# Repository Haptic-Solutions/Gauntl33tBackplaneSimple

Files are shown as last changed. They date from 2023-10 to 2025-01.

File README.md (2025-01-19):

# Gauntl33tBackplaneSimple
 Simple backplane for controlling Brushless DC Gimbal motors in haptic gloves or other devices, designed at the end of 2022.  No active or passive components, just connectors.  In the future will likely make upgrades, such as taking advantage of soft I2C, but keep the board as a simple backplane.

 The Board uses SimpleFOC Mini drivers and Teensy 4.0s for controllers.

 3D Models on Printables: https://www.printables.com/model/366681-gauntl33t

 Firmware: https://github.com/Haptic-Solutions/Gauntl33tFirmware

 Demo Game: https://github.com/Haptic-Solutions/DartsGame

 Haptic Solutions Website: https://hapticsol.com

 Haptic Solutions Discord: https://discord.gg/QZYmbjJW

 Haptic Solutions Twitter: https://twitter.com/Hapticsol

 Peter Sassaman's Twitter: https://twitter.com/PeterSassaman

 Peter Sassaman's TikTok: https://www.tiktok.com/t/ZPR7QYvvF/

Link to page about SimpleFOCMini:
https://docs.simplefoc.com/simplefocmini

Link to oage about SimpleFOC:
https://simplefoc.com/

 Buy SimpleFOCMini Drivers: https://a.aliexpress.com/_mtwToBu

 Link to page about Teensy 4.0: https://www.pjrc.com/store/teensy40.html

 Buy Teensy 4.0: https://a.co/d/iZoN8jr

 Micro PSU which could be used with design to make it smaller: https://github.com/Haptic-Solutions/MicroPSU

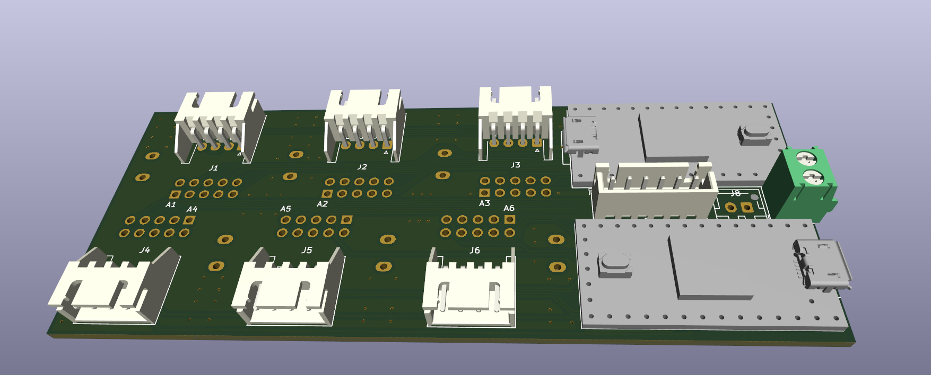
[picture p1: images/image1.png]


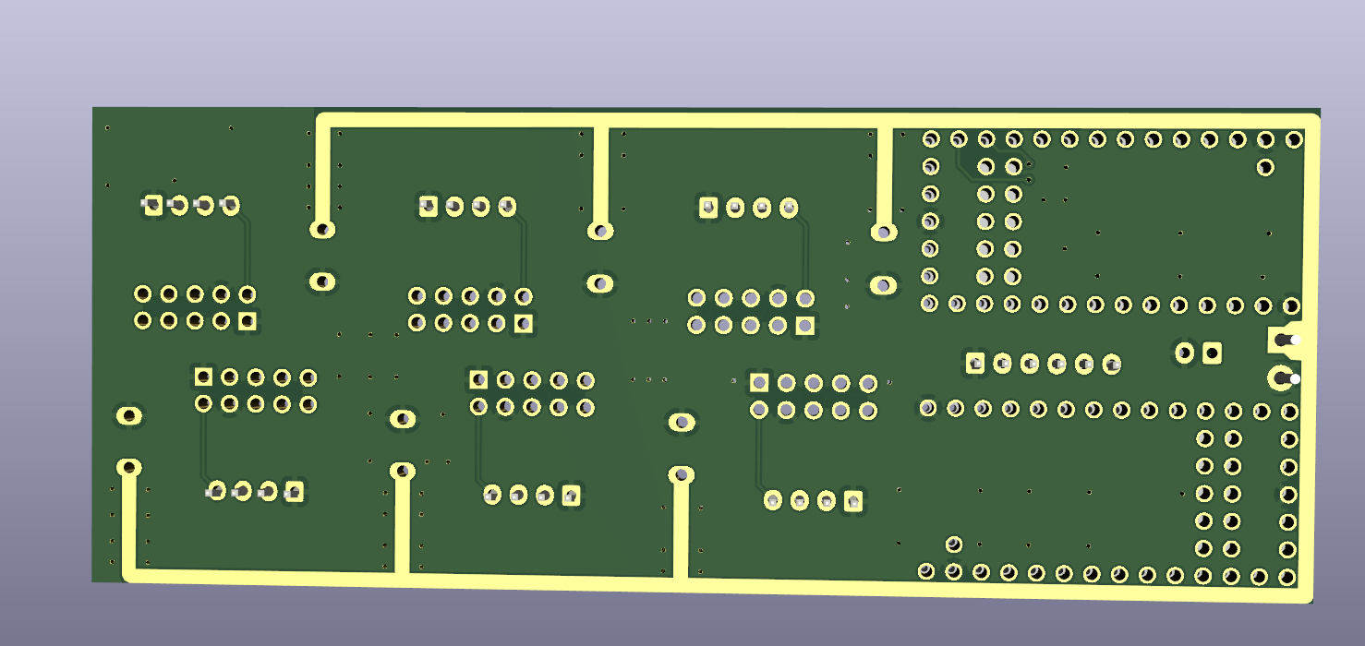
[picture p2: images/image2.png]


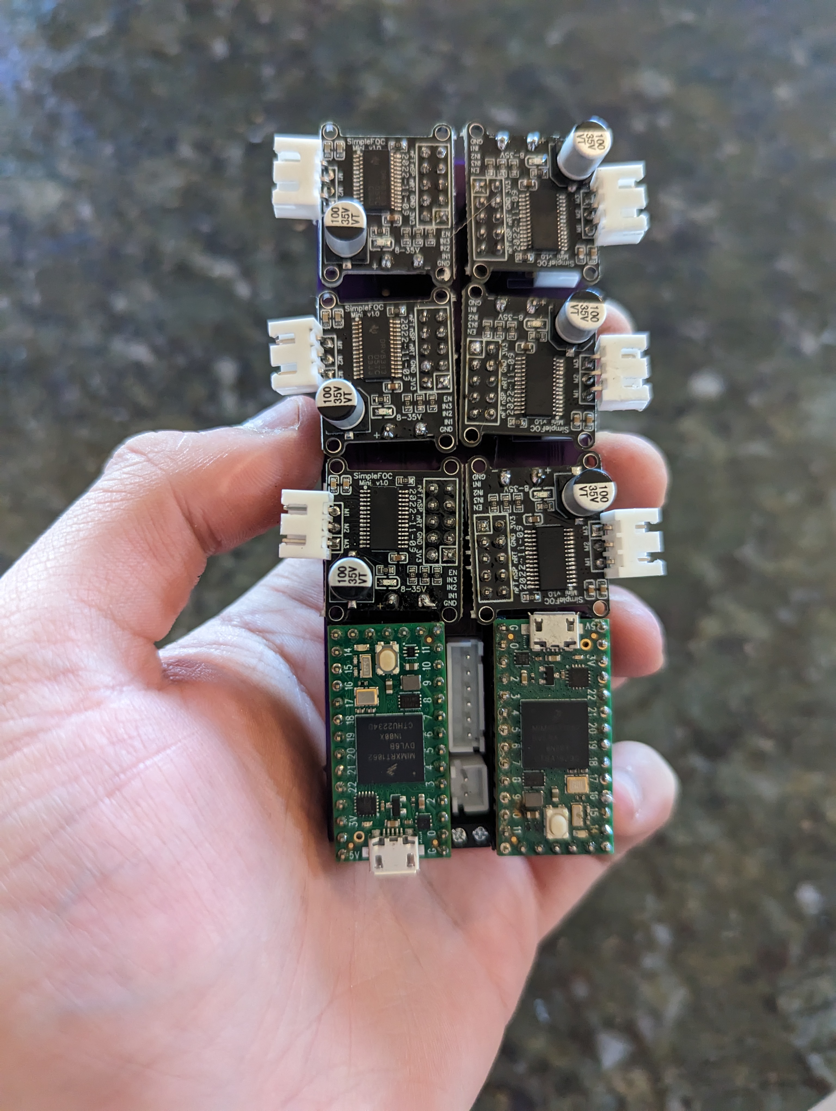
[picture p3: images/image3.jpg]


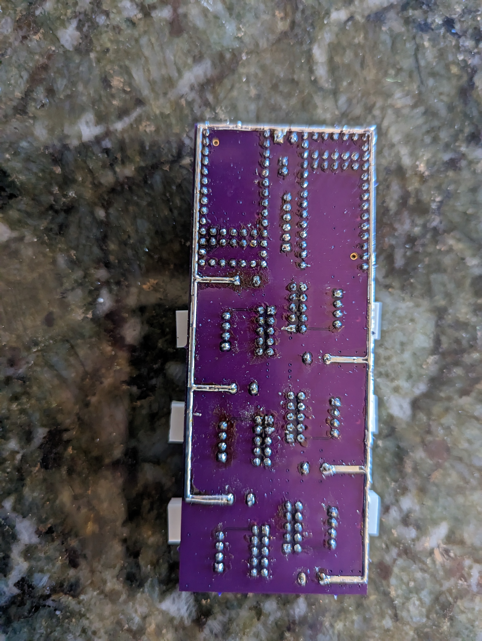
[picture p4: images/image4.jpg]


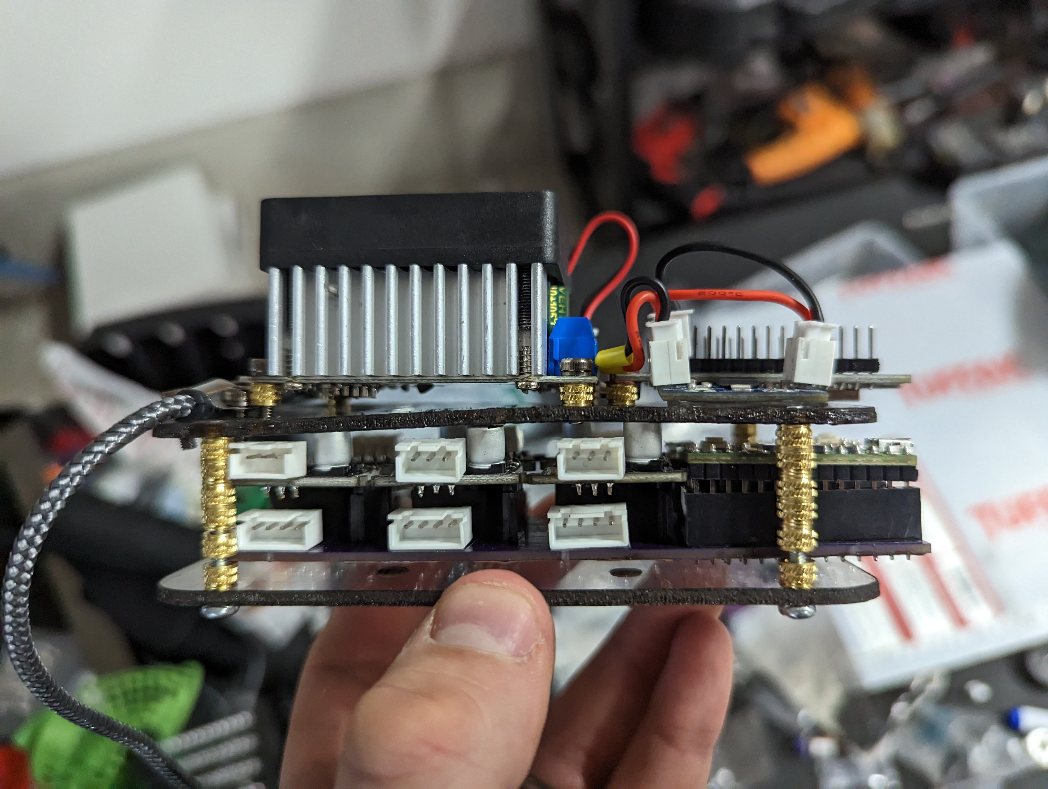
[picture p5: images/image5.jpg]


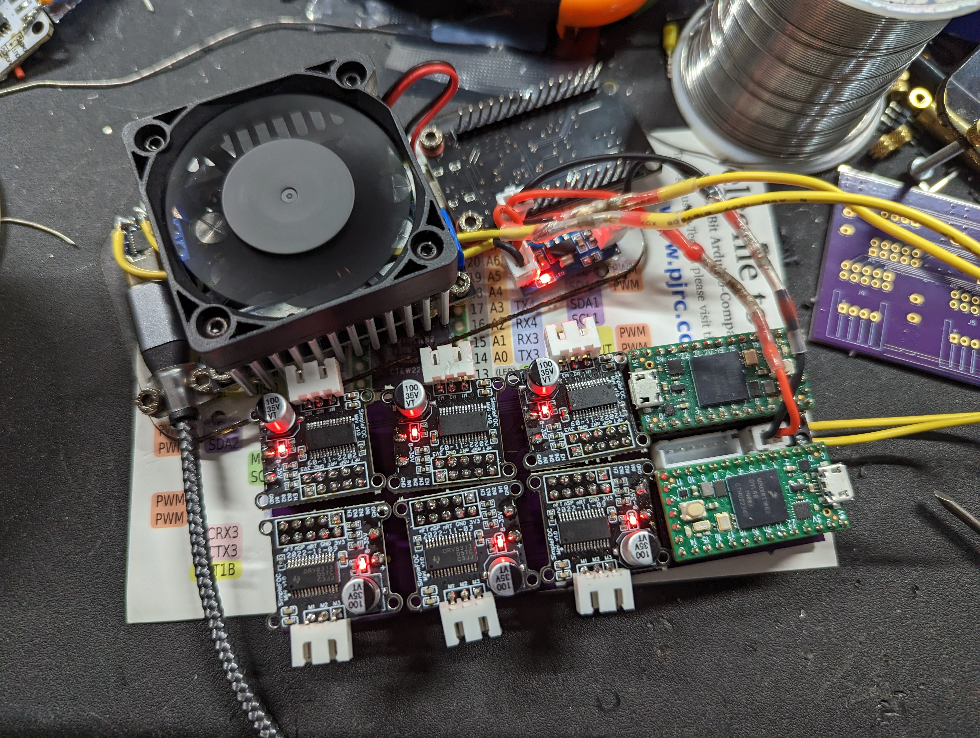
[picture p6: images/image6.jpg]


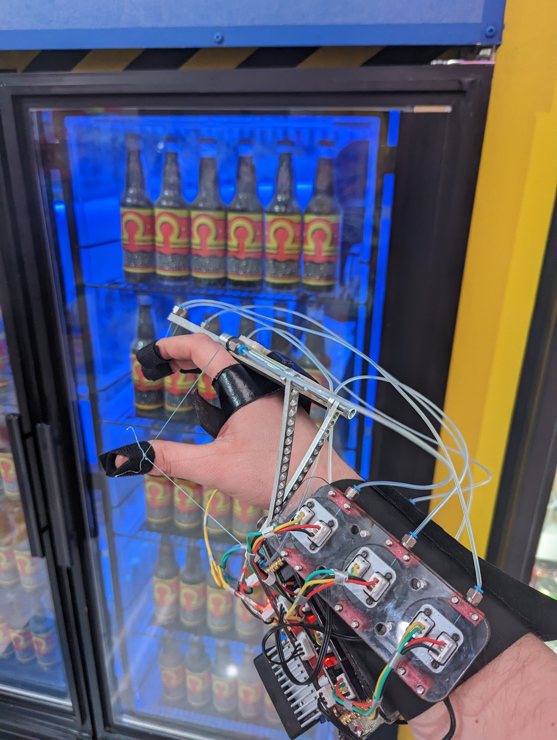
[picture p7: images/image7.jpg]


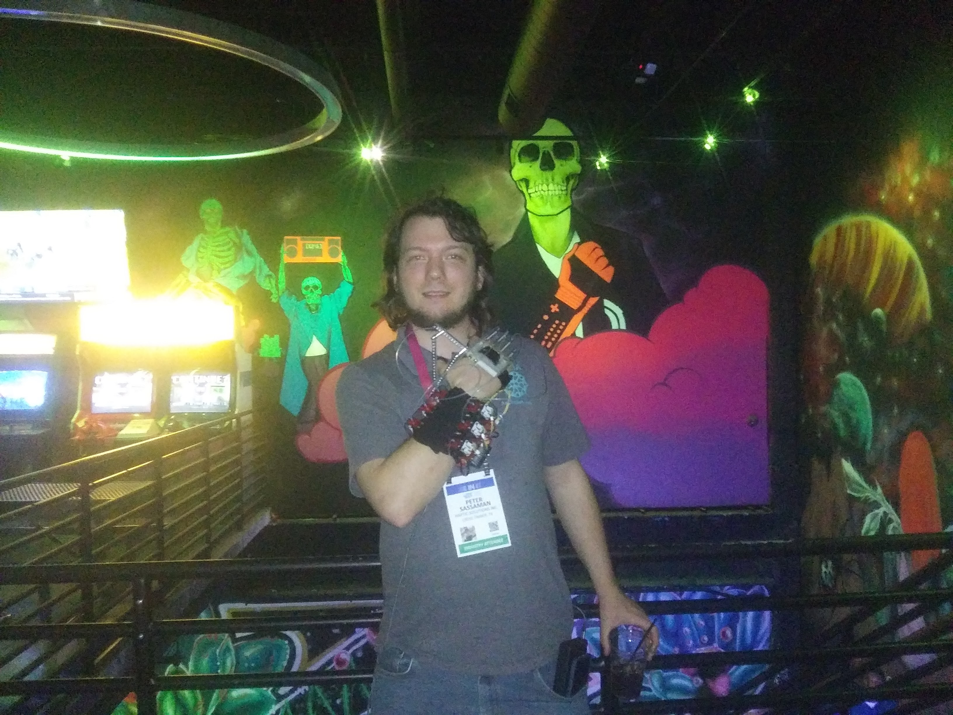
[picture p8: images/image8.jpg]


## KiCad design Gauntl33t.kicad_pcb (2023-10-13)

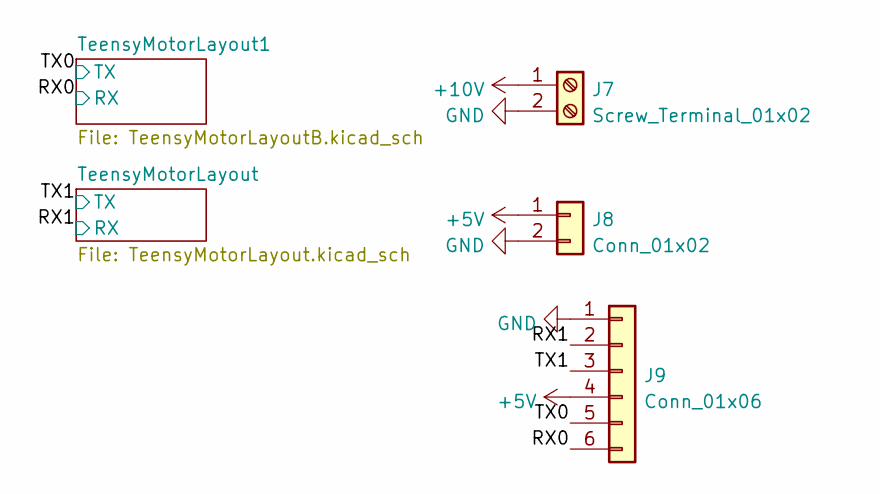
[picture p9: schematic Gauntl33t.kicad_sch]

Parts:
J7: Screw_Terminal_01x02; TerminalBlock_Phoenix_PT-1,5-2-3.5-H_1x02_P3.50mm_Horizontal
J8: Conn_01x02; JST_XH_B2B-XH-AM_1x02_P2.50mm_Vertical
J9: Conn_01x06; JST_XH_B6B-XH-A_1x06_P2.50mm_Vertical

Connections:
+5V: J8.1, J9.4; also elsewhere on the board
+10V: J7.1; also elsewhere on the board
/RX0: J9.6; also elsewhere on the board
/RX1: J9.2; also elsewhere on the board
/TX0: J9.5; also elsewhere on the board
/TX1: J9.3; also elsewhere on the board
GND: J7.2, J8.2, J9.1; also elsewhere on the board

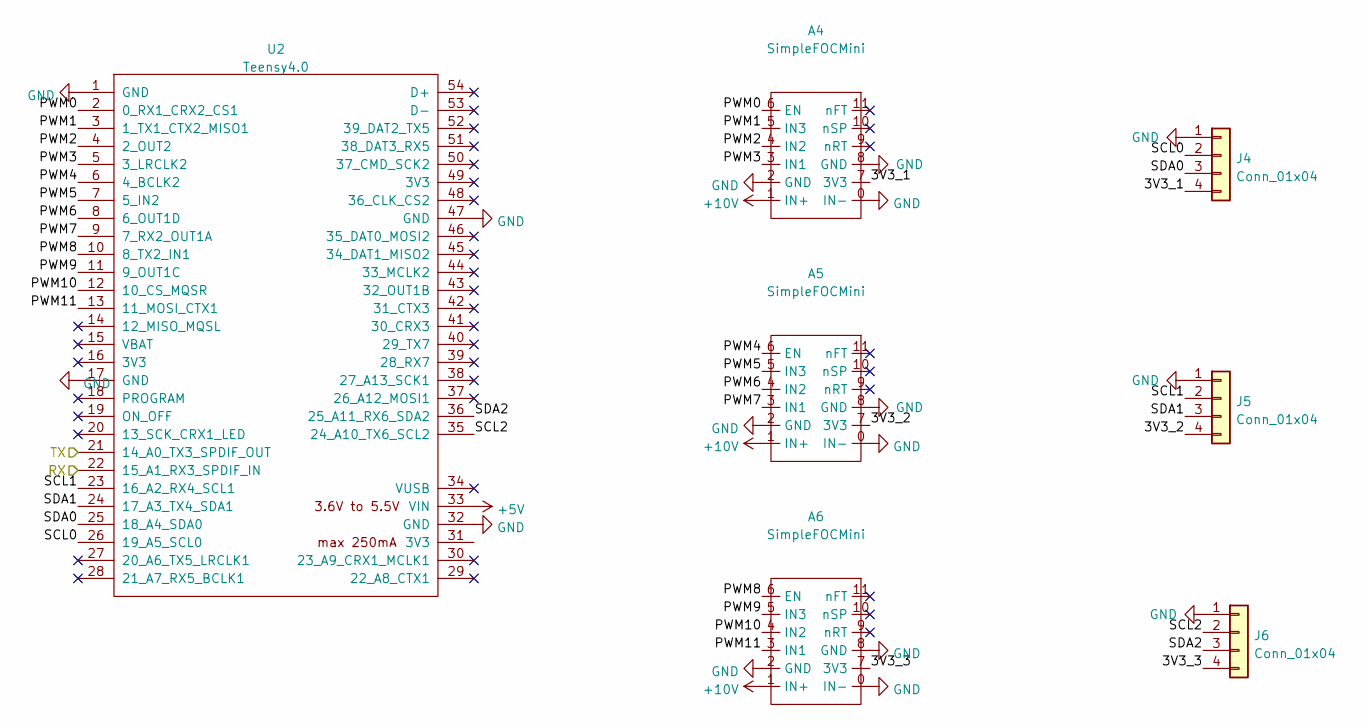
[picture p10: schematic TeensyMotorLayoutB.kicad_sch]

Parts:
A4, A5, A6: SimpleFOCMini
J4, J5, J6: Conn_01x04; JST_XH_S4B-XH-A-1_1x04_P2.50mm_Horizontal
U2: Teensy4.0; Teensy40

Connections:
+5V: U2.33 (VIN); also elsewhere on the board
+10V: A4.1 (IN+), A5.1 (IN+), A6.1 (IN+); also elsewhere on the board
/RX0: U2.22 (15_A1_RX3_SPDIF_IN); also elsewhere on the board
/TX0: U2.21 (14_A0_TX3_SPDIF_OUT); also elsewhere on the board
/TeensyMotorLayout1/3V3_1: A4.7 (3V3), J4.4
/TeensyMotorLayout1/3V3_2: A5.7 (3V3), J5.4
/TeensyMotorLayout1/3V3_3: A6.7 (3V3), J6.4
/TeensyMotorLayout1/PWM0: A4.6 (EN), U2.2 (0_RX1_CRX2_CS1)
/TeensyMotorLayout1/PWM1: A4.5 (IN3), U2.3 (1_TX1_CTX2_MISO1)
/TeensyMotorLayout1/PWM2: A4.4 (IN2), U2.4 (2_OUT2)
/TeensyMotorLayout1/PWM3: A4.3 (IN1), U2.5 (3_LRCLK2)
/TeensyMotorLayout1/PWM4: A5.6 (EN), U2.6 (4_BCLK2)
/TeensyMotorLayout1/PWM5: A5.5 (IN3), U2.7 (5_IN2)
/TeensyMotorLayout1/PWM6: A5.4 (IN2), U2.8 (6_OUT1D)
/TeensyMotorLayout1/PWM7: A5.3 (IN1), U2.9 (7_RX2_OUT1A)
/TeensyMotorLayout1/PWM8: A6.6 (EN), U2.10 (8_TX2_IN1)
/TeensyMotorLayout1/PWM9: A6.5 (IN3), U2.11 (9_OUT1C)
/TeensyMotorLayout1/PWM10: A6.4 (IN2), U2.12 (10_CS_MQSR)
/TeensyMotorLayout1/PWM11: A6.3 (IN1), U2.13 (11_MOSI_CTX1)
/TeensyMotorLayout1/SCL0: J4.2, U2.26 (19_A5_SCL0)
/TeensyMotorLayout1/SCL1: J5.2, U2.23 (16_A2_RX4_SCL1)
/TeensyMotorLayout1/SCL2: J6.2, U2.35 (24_A10_TX6_SCL2)
/TeensyMotorLayout1/SDA0: J4.3, U2.25 (18_A4_SDA0)
/TeensyMotorLayout1/SDA1: J5.3, U2.24 (17_A3_TX4_SDA1)
/TeensyMotorLayout1/SDA2: J6.3, U2.36 (25_A11_RX6_SDA2)
GND: A4.0 (IN-), A4.2 (GND), A4.8 (GND), A5.0 (IN-), A5.2 (GND), A5.8 (GND), A6.0 (IN-), A6.2 (GND), A6.8 (GND), J4.1, J5.1, J6.1, U2.1 (GND), U2.17 (GND), U2.32 (GND), U2.47 (GND); also elsewhere on the board

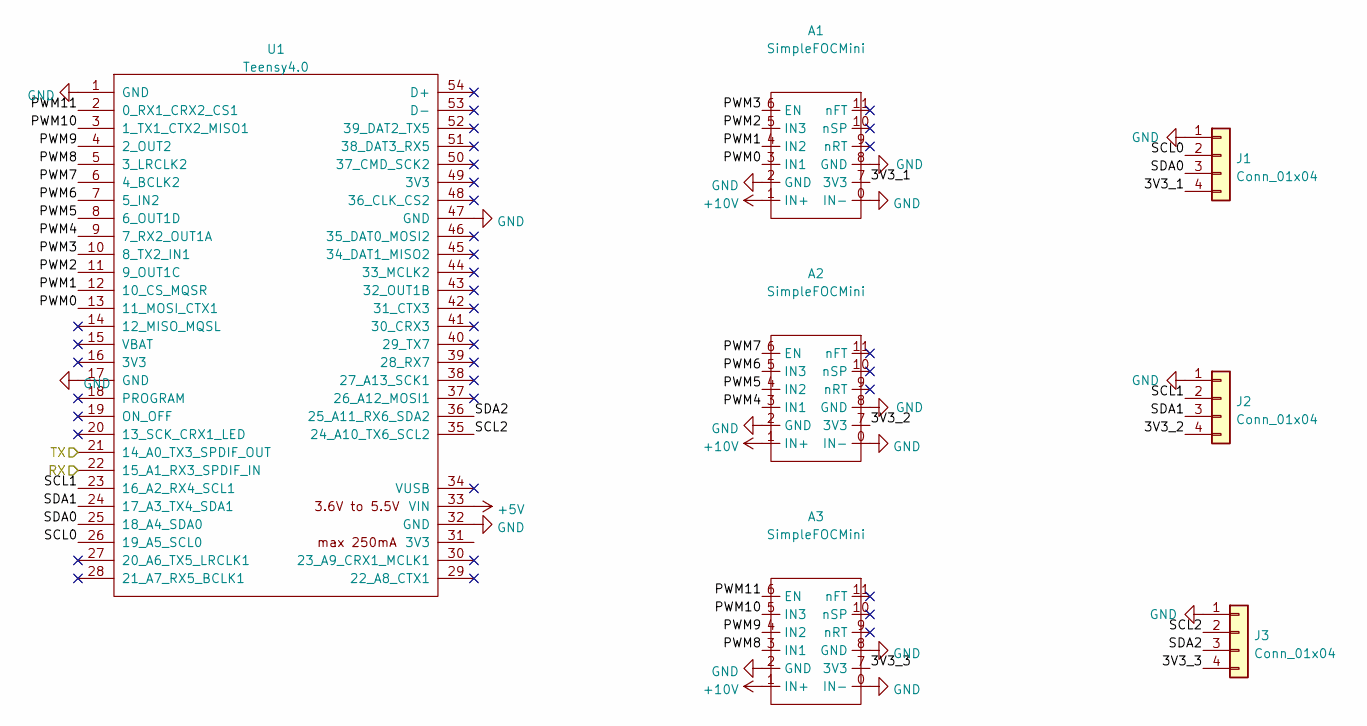
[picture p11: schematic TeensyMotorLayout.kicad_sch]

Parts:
A1, A2, A3: SimpleFOCMini
J1, J2, J3: Conn_01x04; JST_XH_S4B-XH-A-1_1x04_P2.50mm_Horizontal
U1: Teensy4.0; Teensy40

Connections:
+5V: U1.33 (VIN); also elsewhere on the board
+10V: A1.1 (IN+), A2.1 (IN+), A3.1 (IN+); also elsewhere on the board
/RX1: U1.22 (15_A1_RX3_SPDIF_IN); also elsewhere on the board
/TX1: U1.21 (14_A0_TX3_SPDIF_OUT); also elsewhere on the board
/TeensyMotorLayout/3V3_1: A1.7 (3V3), J1.4
/TeensyMotorLayout/3V3_2: A2.7 (3V3), J2.4
/TeensyMotorLayout/3V3_3: A3.7 (3V3), J3.4
/TeensyMotorLayout/PWM0: A1.3 (IN1), U1.13 (11_MOSI_CTX1)
/TeensyMotorLayout/PWM1: A1.4 (IN2), U1.12 (10_CS_MQSR)
/TeensyMotorLayout/PWM2: A1.5 (IN3), U1.11 (9_OUT1C)
/TeensyMotorLayout/PWM3: A1.6 (EN), U1.10 (8_TX2_IN1)
/TeensyMotorLayout/PWM4: A2.3 (IN1), U1.9 (7_RX2_OUT1A)
/TeensyMotorLayout/PWM5: A2.4 (IN2), U1.8 (6_OUT1D)
/TeensyMotorLayout/PWM6: A2.5 (IN3), U1.7 (5_IN2)
/TeensyMotorLayout/PWM7: A2.6 (EN), U1.6 (4_BCLK2)
/TeensyMotorLayout/PWM8: A3.3 (IN1), U1.5 (3_LRCLK2)
/TeensyMotorLayout/PWM9: A3.4 (IN2), U1.4 (2_OUT2)
/TeensyMotorLayout/PWM10: A3.5 (IN3), U1.3 (1_TX1_CTX2_MISO1)
/TeensyMotorLayout/PWM11: A3.6 (EN), U1.2 (0_RX1_CRX2_CS1)
/TeensyMotorLayout/SCL0: J1.2, U1.26 (19_A5_SCL0)
/TeensyMotorLayout/SCL1: J2.2, U1.23 (16_A2_RX4_SCL1)
/TeensyMotorLayout/SCL2: J3.2, U1.35 (24_A10_TX6_SCL2)
/TeensyMotorLayout/SDA0: J1.3, U1.25 (18_A4_SDA0)
/TeensyMotorLayout/SDA1: J2.3, U1.24 (17_A3_TX4_SDA1)
/TeensyMotorLayout/SDA2: J3.3, U1.36 (25_A11_RX6_SDA2)
GND: A1.0 (IN-), A1.2 (GND), A1.8 (GND), A2.0 (IN-), A2.2 (GND), A2.8 (GND), A3.0 (IN-), A3.2 (GND), A3.8 (GND), J1.1, J2.1, J3.1, U1.1 (GND), U1.17 (GND), U1.32 (GND), U1.47 (GND); also elsewhere on the board

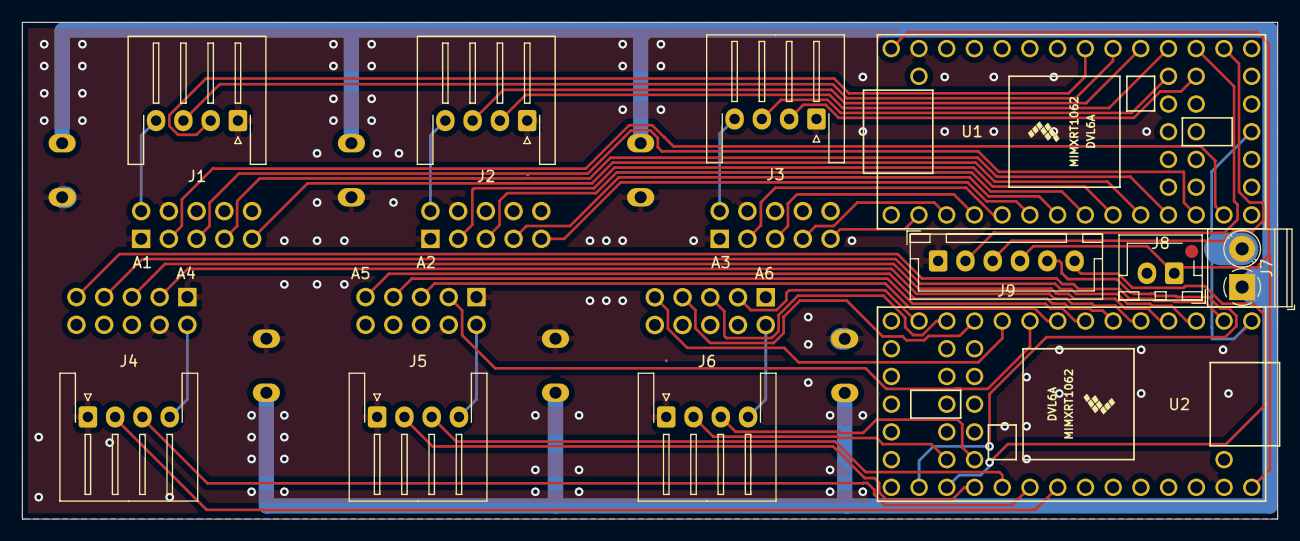
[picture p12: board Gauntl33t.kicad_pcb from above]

Board: 2 copper layers, 115.0 x 45.5 mm, 17 parts (0 on the bottom side), 49 nets.
